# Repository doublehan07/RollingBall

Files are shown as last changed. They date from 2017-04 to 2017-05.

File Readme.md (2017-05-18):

# RollingBall
RollingBall is a 10cm ball which will tonggle led status between lighting on & off when collides with other objects.

## Introduction
Any difference of acceleration in 50ms larger than 15 times scaler will account for a blink event. Then all leds will tonggle lighting status.

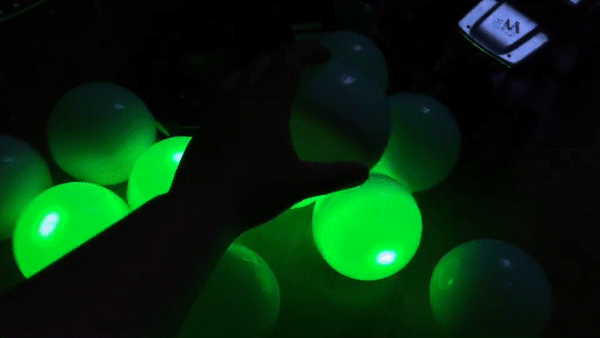
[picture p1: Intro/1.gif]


Things get more interesting when the number of balls increases.



## Important Project files
1. [PDF](/Boards/RollingBallMainBoard/RollingBallMainBoard.pdf) project files

2. [Gerber](/Boards/RollingBallMainBoard/Project_Outputs_for_RollingBallMainBoard.zip) files (zip file)

3. Pin Assignment

|Pin	|	Function		|
|---|---|
|PA8	|	LED array 1		|
|PA11	|	LED array 2		|
|PA12	|	LED array 3		|
|PA15	|	LED array 4		|
|PC13	|	Debug LED		|
|PB8	|	SCL(Software Simulated)	|
|PB9	|	SDA(Software Simulated)	|
|PB5	|	EXTI9_5(MPU6050_INT)	|
|PA9	|	USART1_TX		|
|PA10	|	USART1_RX		|
|PA13	|	SWDIO			|
|PA14	|	SWCLK			|

## Solution details
These basic modules are demanded.
- 1 * Gashapon Shell(White)
- 2 * Li-polymer Battery
- 1 * RollingBall Mainboard

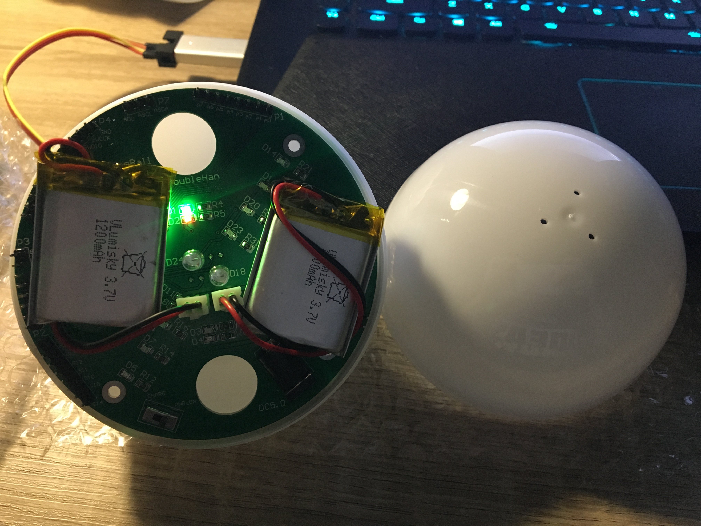
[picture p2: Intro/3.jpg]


On each side, there includes:
- 8 * 0805 led
- 2 * 5mm led

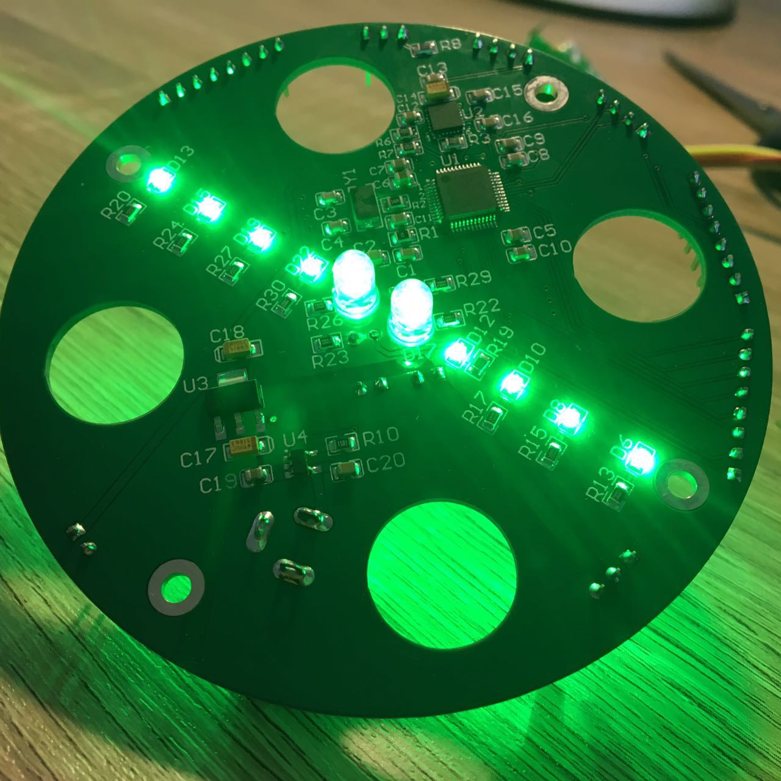
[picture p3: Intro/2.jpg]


***stm32f103c8t6*** is the main controller. 

A inertial measurement unit(imu) ***mpu6050*** will update ball's motion status(i.e. 3 axis of acceleration values).

For charging purpose, the ***tp4054*** is selected.



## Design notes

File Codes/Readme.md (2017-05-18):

# Codes
***stm32f103c8t6*** source codes here.

## Pin assignment
### LED
|Pin	|	Function	|
|---|---|
|PA8	|	LED array 1	|
|PA11	|	LED array 2	|
|PA12	|	LED array 3	|
|PA15	|	LED array 4	|
|PC13	|	Debug LED	|

### MPU6050 Connection
|Pin	|	Function		|
|---|---|
|PB8	|	SCL(Software Simulated)	|
|PB9	|	SDA(Software Simulated)	|
|PB5	|	EXTI9_5(MPU6050_INT)	|

### Debug
|Pin	|	Function	|
|---|---|
|PA9	|	USART1_TX	|
|PA10	|	USART1_RX	|
|PA13	|	SWDIO		|
|PA14	|	SWCLK		|

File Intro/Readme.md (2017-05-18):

# Intro
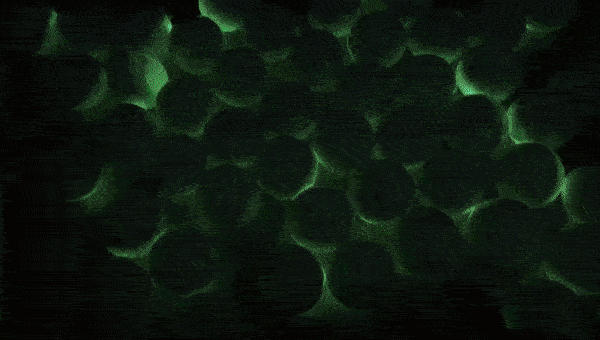
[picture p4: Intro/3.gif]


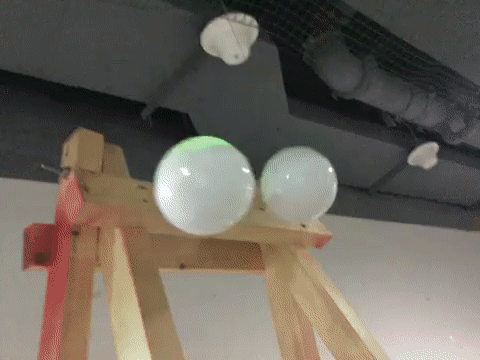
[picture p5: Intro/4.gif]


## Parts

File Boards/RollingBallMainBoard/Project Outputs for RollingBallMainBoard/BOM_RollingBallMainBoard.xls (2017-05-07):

Comment | Description | Designator | Footprint | LibRef | Quantity
10uF (106) ±10% 16V | 钽电容 | C14, C17, C18 | LC-CASE-A_3216 | 3216 10uF (106) 10% 16V | 3
10nF (103) 10% 50V | 贴片电容 | C1, C16 | LC-0805_C | 0805 10nF (103) 10% 50V | 2
1uF (105) 10% 50V | 贴片电容 | C2, C20 | LC-0805_C | 0805 1uF (105) 10% 50V | 2
20pF (200) 5% 50V | 贴片电容 | C3, C4 | LC-0805_C | 0805 20pF (200) 5% 50V | 2
100nF(104) 10% 50V | 贴片电容 | C5, C7, C8, C9, C10, C11, C13, C15 | LC-0805_C | 0805 100nF(104) 10% 50V | 8
4.7uF (475) 10% 25V | 贴片电容 | C6 | LC-0805_C | 0805 4.7uF (475) 10% 25V | 1
2.2nF (222) 5% 50V | 贴片电容 | C12 | LC-0805_C | 0805 2.2nF (222) 5% 50V | 1
10uF (106) 10% 25V | 贴片电容 | C19 | LC-0805_C | 0805 10uF (106) 10% 25V | 1
翠绿 0805 | 发光二极管 | D1, D3, D5, D6, D7, D8, D9, D10, D11, D12, D13, D14, D15, D16, D19, D20, D22, D23 | LC-0805_LED_S1 | 0805 翠绿 | 18
红灯 0805 | 发光二极管 | D2, D4 | LC-0805_LED_S1 | 0805 红灯 | 2
LED0 | 5mm高亮白发绿led | D17, D18, D21, D24 | LED_A2 | LED0 | 4
PWRCON | DC5.5*2.1 | J1 | DC-005 | PWRCON | 1
PA_L | Header, 8-Pin | P1 | HDR1X8 | Header 8 | 1
PB_H | Header, 8-Pin | P2 | HDR1X8 | Header 8 | 1
PB_L | Header, 8-Pin | P3 | HDR1X8 | Header 8 | 1
SWD | 接插件 | P4 | HDR4X1-2.54 | Header 4 | 1
UART | 接插件 | P5 | HDR4X1-2.54 | Header 4 | 1
PWR | 接插件 | P6 | HDR2X1-2.54 | Header 2 | 1
AUX | 接插件 | P7 | HDR3X1-2.54 | Header 3 | 1
BAT1 | 接插件 | P8 | HDR2X1-2.54 | Header 2 | 1
BAT2 | 接插件 | P9 | HDR2X1-2.54 | Header 2 | 1
0Ω (0R0) ±1% | 贴片电阻 | R1 | LC-0805_R | 0805 0Ω (0R0) 1% | 1
NC | 贴片电阻 | R2 | LC-0805_R | 0805 1MΩ (1004) 1% | 1
1KΩ (1001) ±1% | 贴片电阻 | R3, R4, R5, R8, R9, R11 | LC-0805_R | 0805 1KΩ (1001) 1% | 6
4.7KΩ (4701) ±1% | 贴片电阻 | R6, R7 | LC-0805_R | 0805 4.7KΩ (4701) 1% | 2
1.5KΩ (1501) ±1% | 贴片电阻 | R10 | LC-0805_R | 0805 1.5KΩ (1501) 1% | 1
200Ω (2000) ±1% | 贴片电阻 | R12, R13, R14, R15, R16, R17, R18, R19, R20, R21, R22, R23, R24, R25, R26, R27, R28, R29, R30, R31 | LC-0805_R | 0805 200Ω (2000) 1% | 20
SS-12D00(1P2T) | 开关 | S1 | XH2.54-3P | SW-SPDT | 1
STM32F103C8T6 | ARM | U1 | LC-LQFP-48_7x7x05P | STM32F103C8T6 | 1
MPU-6050 | 传感器 | U2 | LC-QFN-24_4x4x05P | MPU-6050 | 1
AMS1117-3.3 | 低压差线性稳压(LDO) | U3 | LC-SOT-223 | SOT-223 AMS1117-3.3 | 1
TP4054 | 电池电源管理 | U4 | LC-SOT-23-5 | TP4054 | 1
8MHz ±20ppm 20pF | 贴片晶振 | Y1 | LC-SMD-5032_2P | SMD-5032_2P 8MHz 20ppm 20pF | 1

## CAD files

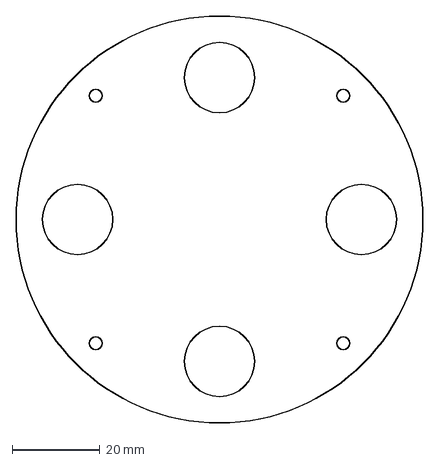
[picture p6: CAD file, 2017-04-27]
Boards/Outline/PCBoutline.dxf
92.6 x 92.6 mm

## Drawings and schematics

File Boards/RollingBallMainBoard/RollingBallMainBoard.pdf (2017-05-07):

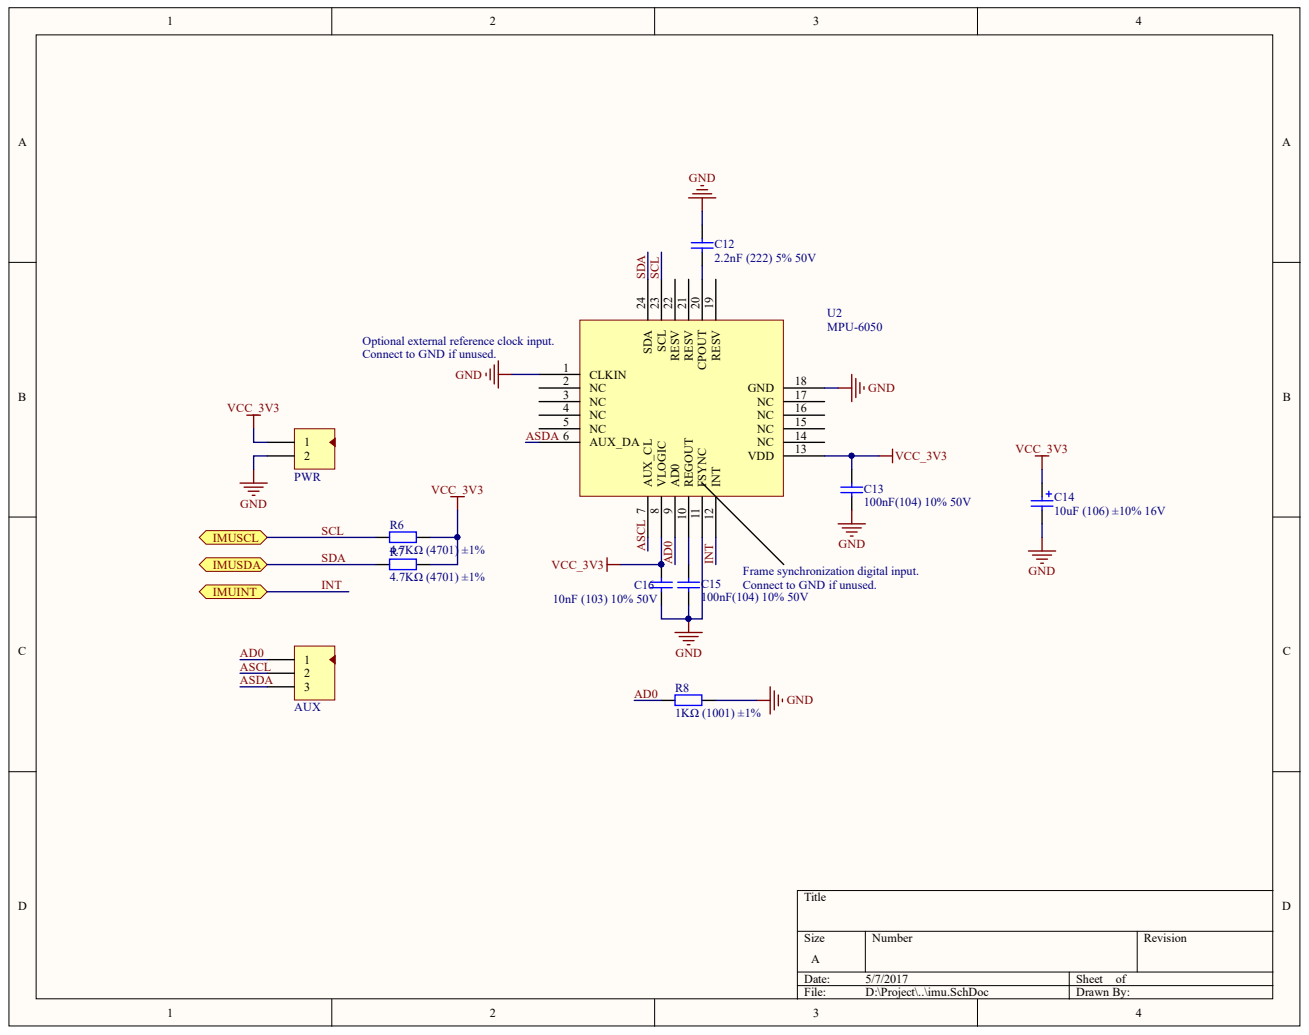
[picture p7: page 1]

RESV 19 CPOUT 20 RESV 21 RESV 22 SCL 23 SDA 24

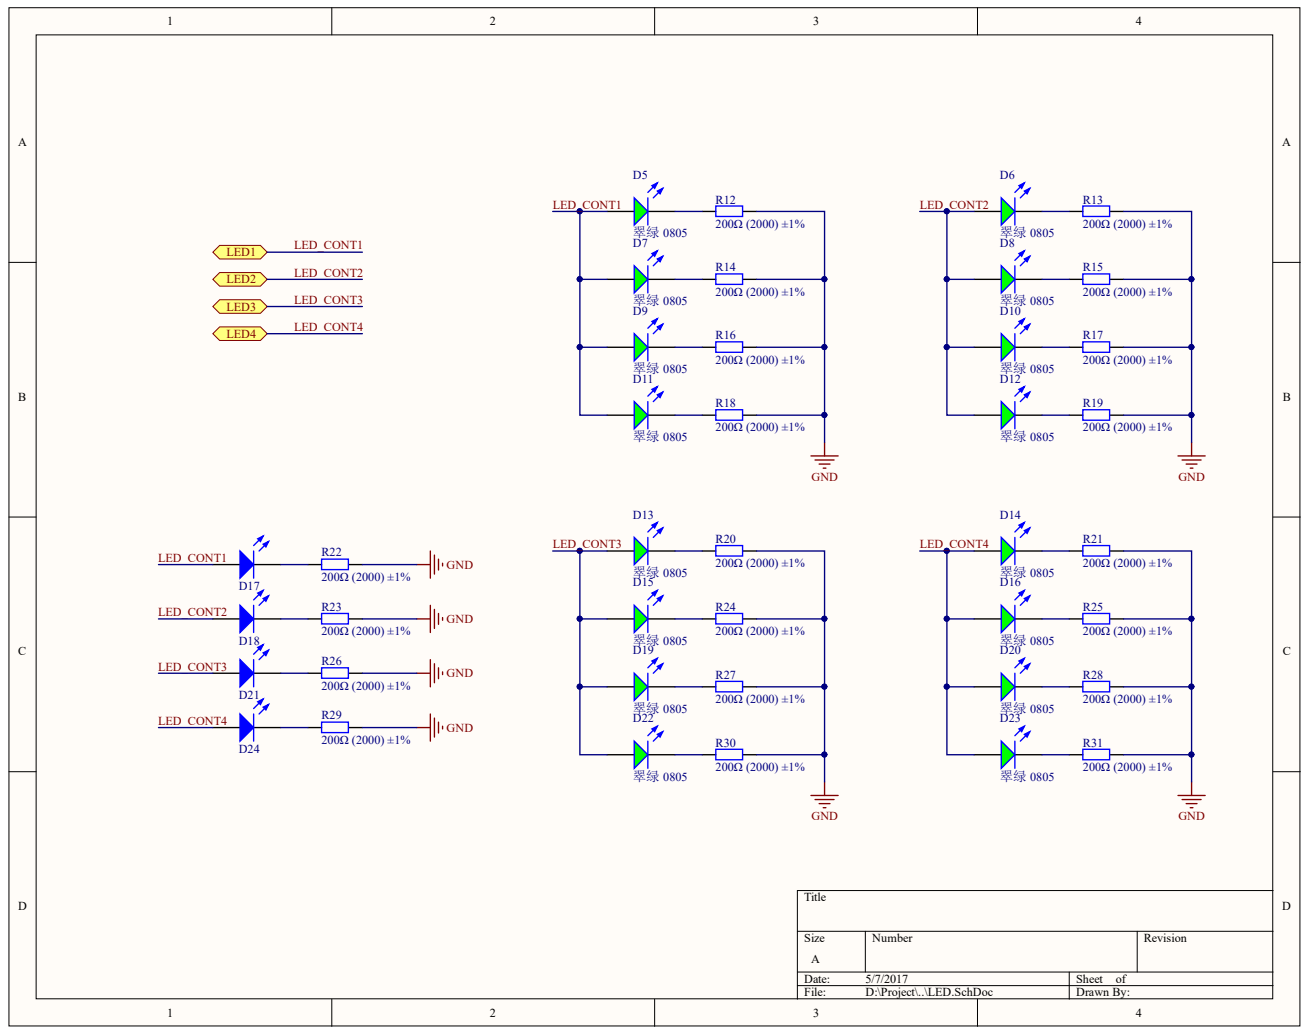
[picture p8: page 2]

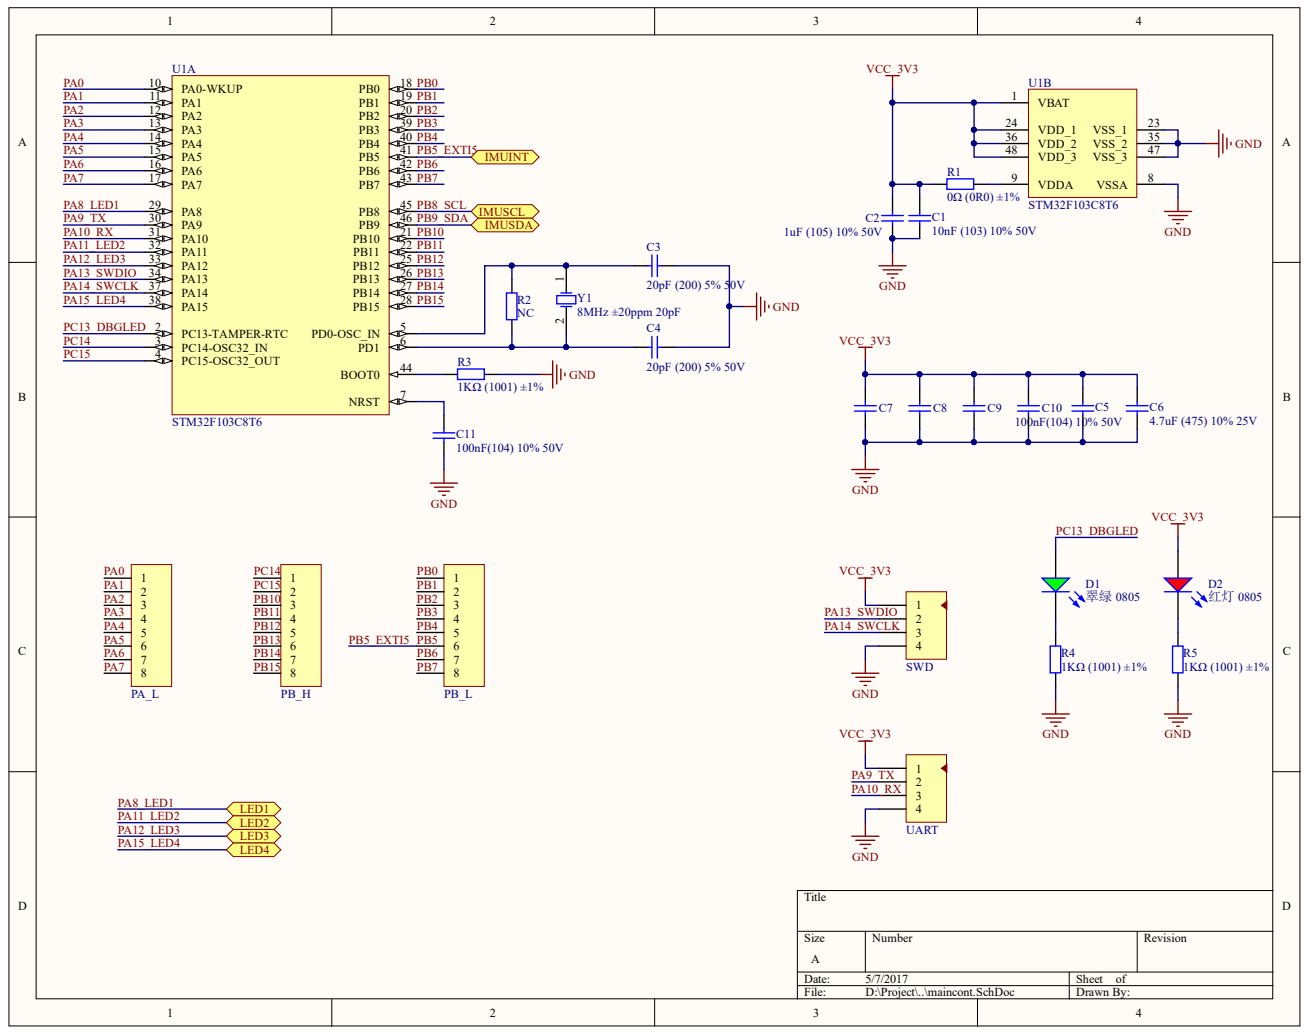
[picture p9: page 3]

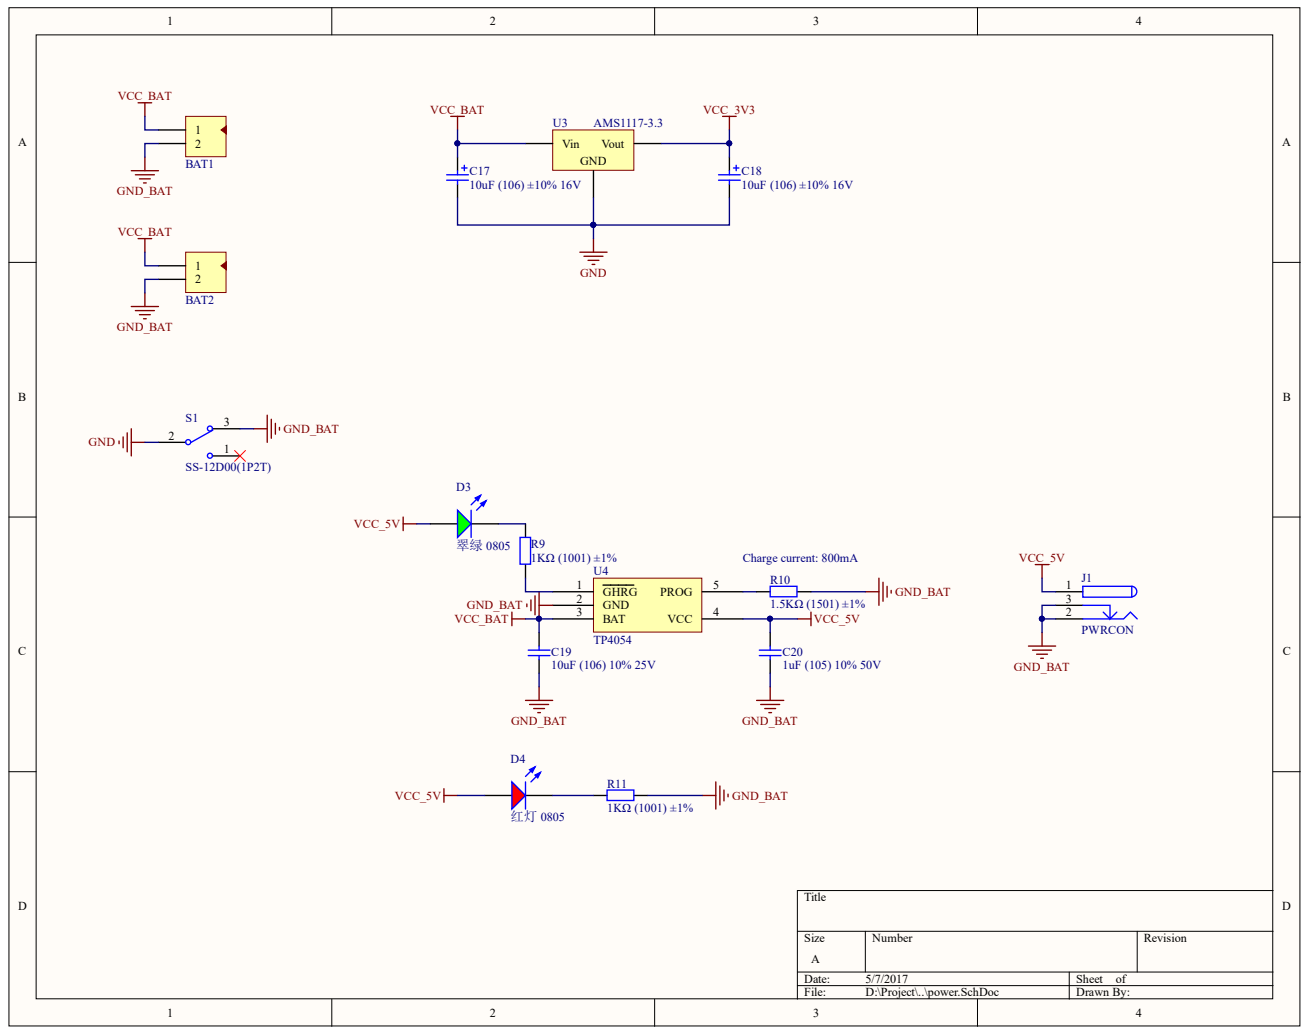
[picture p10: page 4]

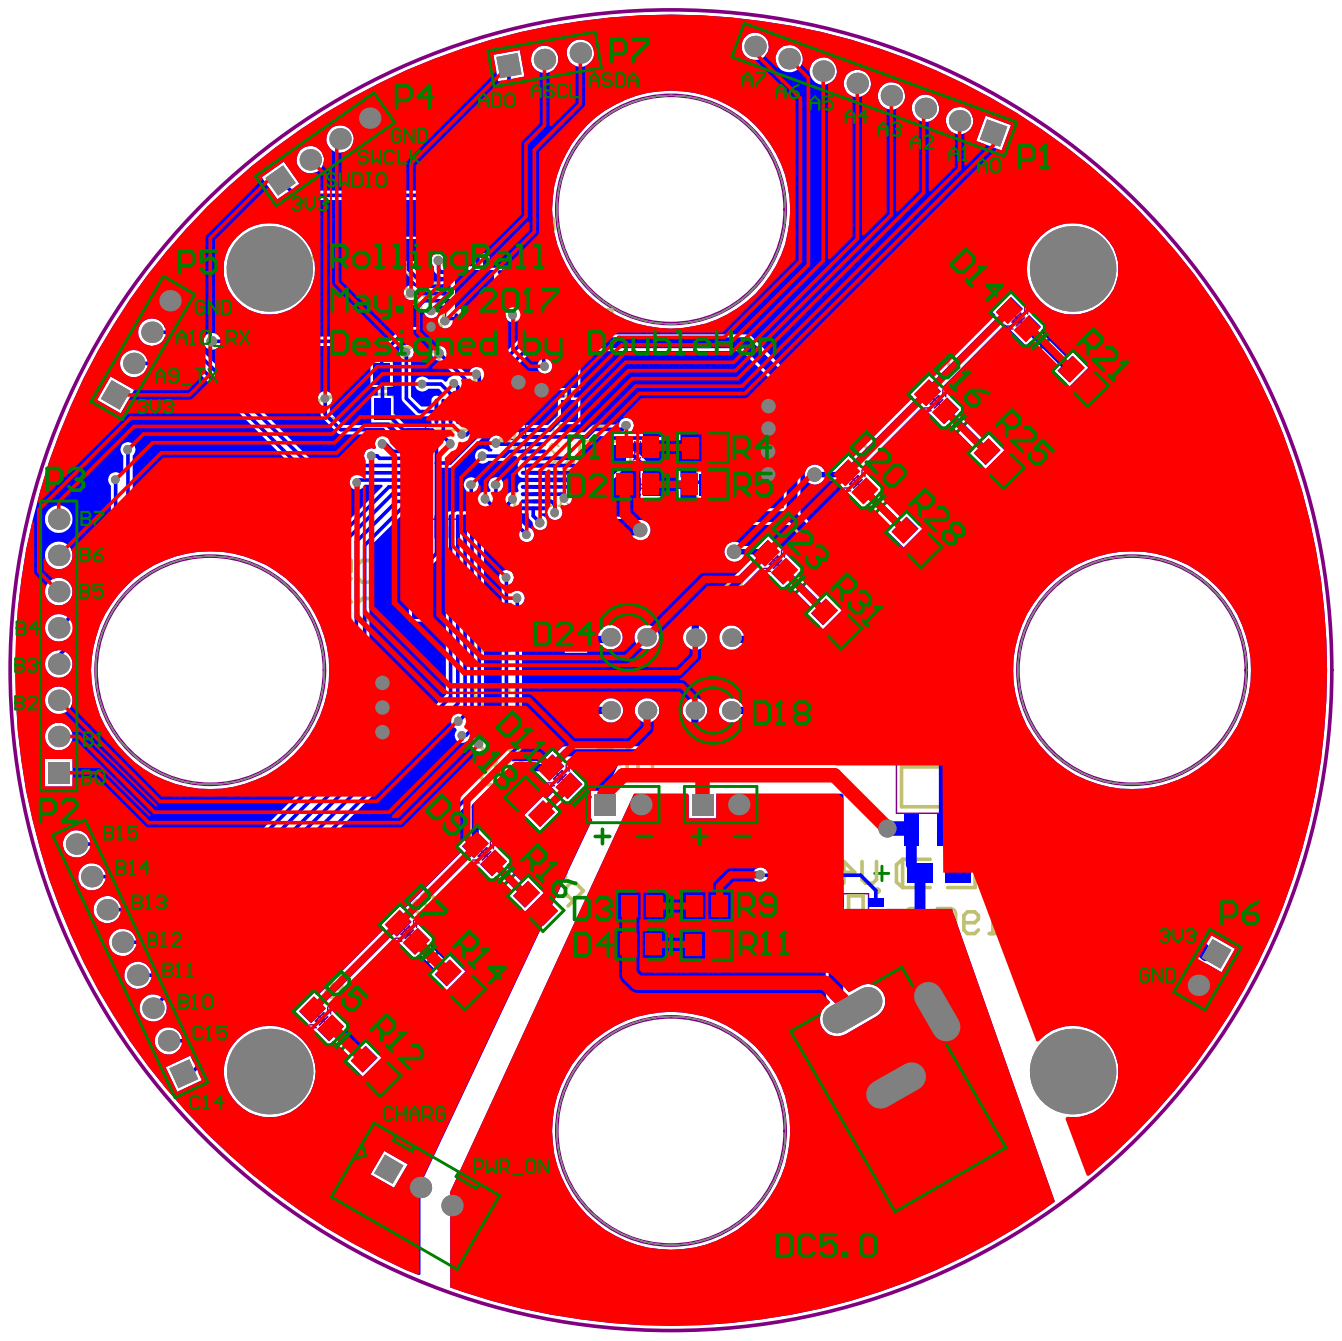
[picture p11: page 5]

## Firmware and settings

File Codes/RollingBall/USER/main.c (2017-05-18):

#include "sys.h"

u8 delay_50,delay_flag;//,Bi_zhang=0;          //默认情况下，不开启避障功能，长按用户按键2s以上可以进入避障模式
int main(void)
{ 
	Stm32_Clock_Init(9);            //=====系统时钟设置
	delay_init(72);                 //=====延时初始化
	//JTAG_Set(JTAG_SWD_DISABLE);     //=====关闭JTAG接口
	JTAG_Set(SWD_ENABLE);           //=====打开SWD接口 可以利用主板的SWD接口调试
	LED_Init();                     //=====初始化与 LED 连接的硬件接口
	uart_init(72,115200);           //=====初始化串口1
	IIC_Init();                     //=====模拟IIC初始化
	
  MPU6050_initialize();           //=====MPU6050初始化	
  DMP_Init();                     //=====初始化DMP     
	
	PAout(8) = 0;
	PAout(11) = 0;
	PAout(12) = 0;
	PAout(15) = 0;
	
	EXTI_Init();                    //=====MPU6050 5ms定时中断初始化
	delay_ms(500);
	PCout(13)= 1;
	
	while(1)
	{     
			  delay_flag=1;	
				delay_50=0;
				while(delay_flag);	     //通过MPU6050的INT中断实现的50ms精准延时				
	} 
}

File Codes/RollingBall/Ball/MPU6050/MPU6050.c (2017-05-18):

#include "MPU6050.h"
#include "IOI2C.h"
#include "usart.h"
#include "RollingBall.h"

#define PRINT_ACCEL     (0x01)
#define PRINT_GYRO      (0x02)
#define PRINT_QUAT      (0x04)
#define ACCEL_ON        (0x01)
#define GYRO_ON         (0x02)
#define MOTION          (0)
#define NO_MOTION       (1)
#define DEFAULT_MPU_HZ  (200)
#define FLASH_SIZE      (512)
#define FLASH_MEM_START ((void*)0x1800)
#define q30  1073741824.0f
short gyro[3], accel[3], sensors;
float q0=1.0f,q1=0.0f,q2=0.0f,q3=0.0f;
static signed char gyro_orientation[9] = {-1, 0, 0,
                                           0,-1, 0,
                                           0, 0, 1};

//#define DATA_DEBUG
#ifdef DATA_DEBUG
static u8 sendPackage[11], i;
static float a = 1.0f;
static float temp;
static short Ynx = 0, Yn_1x = 0, Xnx = 0;
static short Yny = 0, Yn_1y = 0, Xny = 0;
static short Ynz = 0, Yn_1z = 0, Xnz = 0;
#endif
																					 
static  unsigned short inv_row_2_scale(const signed char *row)
{
    unsigned short b;

    if (row[0] > 0)
        b = 0;
    else if (row[0] < 0)
        b = 4;
    else if (row[1] > 0)
        b = 1;
    else if (row[1] < 0)
        b = 5;
    else if (row[2] > 0)
        b = 2;
    else if (row[2] < 0)
        b = 6;
    else
        b = 7;      // error
    return b;
}


static  unsigned short inv_orientation_matrix_to_scalar(
    const signed char *mtx)
{
    unsigned short scalar;
    scalar = inv_row_2_scale(mtx);
    scalar |= inv_row_2_scale(mtx + 3) << 3;
    scalar |= inv_row_2_scale(mtx + 6) << 6;


    return scalar;
}

static void run_self_test(void)
{
    int result;
    long gyro[3], accel[3];

    result = mpu_run_self_test(gyro, accel);
    if (result == 0x7) {
        /* Test passed. We can trust the gyro data here, so let's push it down
         * to the DMP.
         */
        float sens;
        unsigned short accel_sens;
        mpu_get_gyro_sens(&sens);
        gyro[0] = (long)(gyro[0] * sens);
        gyro[1] = (long)(gyro[1] * sens);
        gyro[2] = (long)(gyro[2] * sens);
        dmp_set_gyro_bias(gyro);
        mpu_get_accel_sens(&accel_sens);
        accel[0] *= accel_sens;
        accel[1] *= accel_sens;
        accel[2] *= accel_sens;
        dmp_set_accel_bias(accel);
//		printf("setting bias succesfully ......\r\n");
    }
}



uint8_t buffer[14];

int16_t  MPU6050_FIFO[6][11];
int16_t Gx_offset=0,Gy_offset=0,Gz_offset=0;


/**************************实现函数********************************************
*函数原型:		void  MPU6050_newValues(int16_t ax,int16_t ay,int16_t az,int16_t gx,int16_t gy,int16_t gz)
*功　　能:	    将新的ADC数据更新到 FIFO数组，进行滤波处理
*******************************************************************************/

void  MPU6050_newValues(int16_t ax,int16_t ay,int16_t az,int16_t gx,int16_t gy,int16_t gz)
{
unsigned char i ;
int32_t sum=0;
for(i=1;i<10;i++){	//FIFO 操作
MPU6050_FIFO[0][i-1]=MPU6050_FIFO[0][i];
MPU6050_FIFO[1][i-1]=MPU6050_FIFO[1][i];
MPU6050_FIFO[2][i-1]=MPU6050_FIFO[2][i];
MPU6050_FIFO[3][i-1]=MPU6050_FIFO[3][i];
MPU6050_FIFO[4][i-1]=MPU6050_FIFO[4][i];
MPU6050_FIFO[5][i-1]=MPU6050_FIFO[5][i];
}
MPU6050_FIFO[0][9]=ax;//将新的数据放置到 数据的最后面
MPU6050_FIFO[1][9]=ay;
MPU6050_FIFO[2][9]=az;
MPU6050_FIFO[3][9]=gx;
MPU6050_FIFO[4][9]=gy;
MPU6050_FIFO[5][9]=gz;

sum=0;
for(i=0;i<10;i++){	//求当前数组的合，再取平均值
   sum+=MPU6050_FIFO[0][i];
}
MPU6050_FIFO[0][10]=sum/10;

sum=0;
for(i=0;i<10;i++){
   sum+=MPU6050_FIFO[1][i];
}
MPU6050_FIFO[1][10]=sum/10;

sum=0;
for(i=0;i<10;i++){
   sum+=MPU6050_FIFO[2][i];
}
MPU6050_FIFO[2][10]=sum/10;

sum=0;
for(i=0;i<10;i++){
   sum+=MPU6050_FIFO[3][i];
}
MPU6050_FIFO[3][10]=sum/10;

sum=0;
for(i=0;i<10;i++){
   sum+=MPU6050_FIFO[4][i];
}
MPU6050_FIFO[4][10]=sum/10;

sum=0;
for(i=0;i<10;i++){
   sum+=MPU6050_FIFO[5][i];
}
MPU6050_FIFO[5][10]=sum/10;
}

/**************************实现函数********************************************
*函数原型:		void MPU6050_setClockSource(uint8_t source)
*功　　能:	    设置  MPU6050 的时钟源
 * CLK_SEL | Clock Source
 * --------+--------------------------------------
 * 0       | Internal oscillator
 * 1       | PLL with X Gyro reference
 * 2       | PLL with Y Gyro reference
 * 3       | PLL with Z Gyro reference
 * 4       | PLL with external 32.768kHz reference
 * 5       | PLL with external 19.2MHz reference
 * 6       | Reserved
 * 7       | Stops the clock and keeps the timing generator in reset
*******************************************************************************/
void MPU6050_setClockSource(uint8_t source){
    IICwriteBits(devAddr, MPU6050_RA_PWR_MGMT_1, MPU6050_PWR1_CLKSEL_BIT, MPU6050_PWR1_CLKSEL_LENGTH, source);

}

/** Set full-scale gyroscope range.
 * @param range New full-scale gyroscope range value
 * @see getFullScaleRange()
 * @see MPU6050_GYRO_FS_250
 * @see MPU6050_RA_GYRO_CONFIG
 * @see MPU6050_GCONFIG_FS_SEL_BIT
 * @see MPU6050_GCONFIG_FS_SEL_LENGTH
 */
void MPU6050_setFullScaleGyroRange(uint8_t range) {
    IICwriteBits(devAddr, MPU6050_RA_GYRO_CONFIG, MPU6050_GCONFIG_FS_SEL_BIT, MPU6050_GCONFIG_FS_SEL_LENGTH, range);
}

/**************************实现函数********************************************
*函数原型:		void MPU6050_setFullScaleAccelRange(uint8_t range)
*功　　能:	    设置  MPU6050 加速度计的最大量程
*******************************************************************************/
void MPU6050_setFullScaleAccelRange(uint8_t range) {
    IICwriteBits(devAddr, MPU6050_RA_ACCEL_CONFIG, MPU6050_ACONFIG_AFS_SEL_BIT, MPU6050_ACONFIG_AFS_SEL_LENGTH, range);
}

/**************************实现函数********************************************
*函数原型:		void MPU6050_setSleepEnabled(uint8_t enabled)
*功　　能:	    设置  MPU6050 是否进入睡眠模式
				enabled =1   睡觉
			    enabled =0   工作
*******************************************************************************/
void MPU6050_setSleepEnabled(uint8_t enabled) {
    IICwriteBit(devAddr, MPU6050_RA_PWR_MGMT_1, MPU6050_PWR1_SLEEP_BIT, enabled);
}

/**************************实现函数********************************************
*函数原型:		uint8_t MPU6050_getDeviceID(void)
*功　　能:	    读取  MPU6050 WHO_AM_I 标识	 将返回 0x68
*******************************************************************************/
uint8_t MPU6050_getDeviceID(void) {

    IICreadBytes(devAddr, MPU6050_RA_WHO_AM_I, 1, buffer);
    return buffer[0];
}

/**************************实现函数********************************************
*函数原型:		uint8_t MPU6050_testConnection(void)
*功　　能:	    检测MPU6050 是否已经连接
*******************************************************************************/
uint8_t MPU6050_testConnection(void) {
   if(MPU6050_getDeviceID() == 0x68)  //0b01101000;
   return 1;
   	else return 0;
}
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

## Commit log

2017-04-23 Add stm32 project files.
2017-04-27 Finish pcb design.
    [PCBoutline.dxf, RollingBall.PcbDoc, RollingBallMainBoard.PrjPcb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]
2017-04-27 Add gerber.
    [BOM_RollingBallMainBoard.xlsx, Pick Place for RollingBall.csv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]
2017-05-05 Update codes.
    [PowerManager.SchDoc]
2017-05-07 Update pcb design.
    [BOM_RollingBallMainBoard.xls, BOM_RollingBallMainBoard.xlsx, LED.SchDoc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]
